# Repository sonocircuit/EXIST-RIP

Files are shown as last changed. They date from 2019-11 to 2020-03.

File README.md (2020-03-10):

# EXI[S]T: an adaption of Mannequins' RIP module.

Mannequins RIP module by Whimsical Raps is now [open source](https://github.com/whimsicalraps/RIP_DIY). EXI[S]T is an adaption thereof and can be configured in several ways. The name is a tribute to Meng Qi's module "Please Exist".

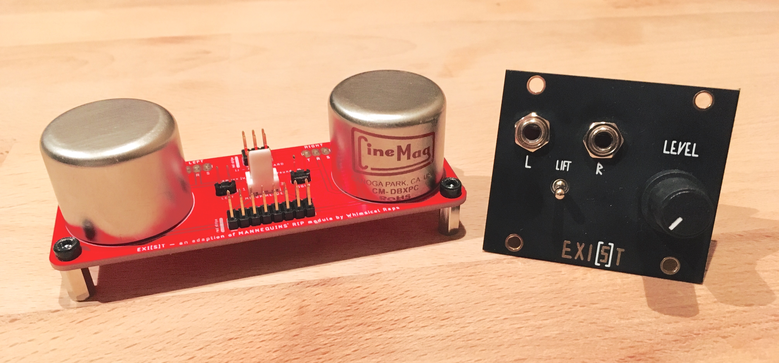
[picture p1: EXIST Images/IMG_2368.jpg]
PCB


## Modes of use

The main PCB – *the transformer board* – is meant to be mounted inside the case. The inputs and outputs can be connected in serveral ways. Any configuration of the listed options below is possible.

**Input option A:** <br> The inputs are conncted to the *transformer board* via 16 pin ribbon cable from the 1u EXI[S]T module. The 1u modules are available in Intellijel (12HP) and Pulplogic (10HP) format and house the input jacks, lift switch and an attenuating volume pot. <br>

**Input option B:** <br> An [Intelligel Mixup](https://intellijel.com/shop/eurorack/mixup) module can be connceted directly to the *transformer board* via the molex 3pin output bus connector. This configuration makes the 1u module redundant and ground lift may be engaged directly on the transformer board with two jumpers.

**Output option A:** <br> TRS Jacks can be connected to the *transformer board* with wires via the "TRS" pads. <br>

**Output option B:** <br> The 6pin header can be connected either to an Intellijel [Audio Jack rev2 board](https://intellijel.com/shop/cases/7u-audio-jacks-board-v2) or an Intellijel [Stereo Line Out Jacks module](https://intellijel.com/shop/eurorack/1u/stereo-line-out-jacks-1u) via 6 pin ribbon cable.

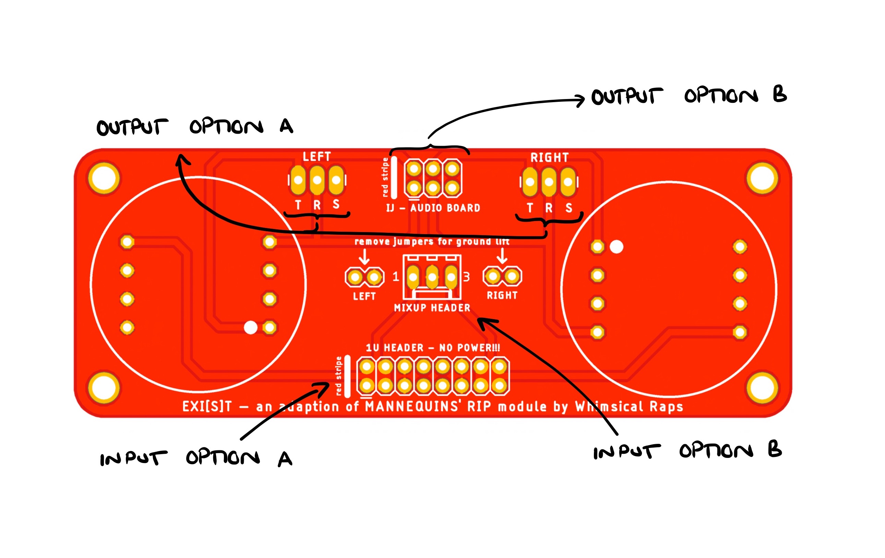
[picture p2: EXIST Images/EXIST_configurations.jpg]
CONFIG


## Make you own

**PCBs:** All [eagle files](https://github.com/sonoCircuits/EXIST-RIP/tree/master/EXIST-EAGLE%20FILES) can be found in the repro in case you wish to have PCB's fabricated.

**BOM:** Here is the [OCTOPART BOM](https://octopart.com/bom-tool/6HVkKHyi). Please note that the silkscreen of the mixup header on the *transformer board* should be rotated by 180° (rotate the header before soldering, otherwise L and R channels will be swapped). The silkscreen has been corrected on the Eagle files.

## Credits

Thanks to [Whimsical Raps](http://whimsicalraps.com) for designing RIP and making the files open source, and to Meng Qi for the name inspiration.

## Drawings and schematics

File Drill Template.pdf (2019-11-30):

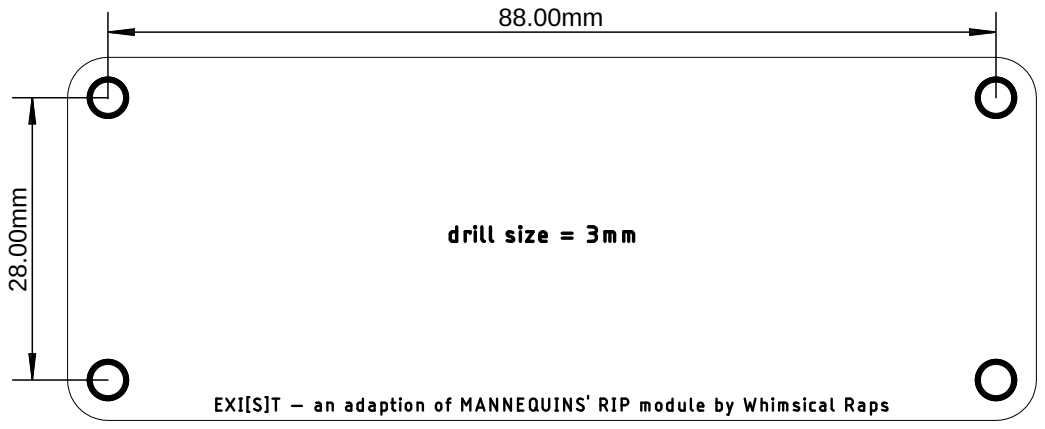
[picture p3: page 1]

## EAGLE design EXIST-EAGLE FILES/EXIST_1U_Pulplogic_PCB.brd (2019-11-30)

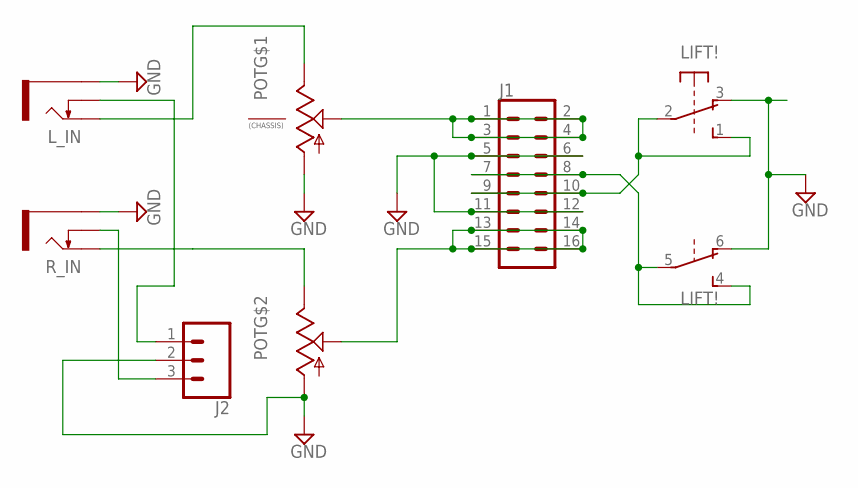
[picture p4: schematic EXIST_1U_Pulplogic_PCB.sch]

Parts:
J1: CONN_08X2; 2X8
J2: CONN_03; 1X03
LIFT!: 9450-2
L_IN: THONKICONNNEW; WQP-PJ301M-12_JACK
POT: ALPHA-9MM-DUALPOT; DUAL_9MM_SNAP-IN_POT
R_IN: THONKICONNNEW; WQP-PJ301M-12_JACK

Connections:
GND: J1.5, J1.6, J1.11, J1.12, J2.2, LIFT!.3 (O), LIFT!.6 (O), L_IN.P$3_SLEEVE (SLEEVE), POT.1 (A), POT.1B (A), R_IN.P$3_SLEEVE (SLEEVE)
unnamed: J1.13, J1.14, J1.15, J1.16, POT.2B (S)
unnamed: J1.1, J1.2, J1.3, J1.4, POT.2 (S)
unnamed: J1.7, J1.8, LIFT!.4 (S), LIFT!.5
unnamed: J2.1, L_IN.P$2_SWITCH (SWITCH)
unnamed: POT.3B (E), R_IN.P$1_TIP (TIP)
unnamed: L_IN.P$1_TIP (TIP), POT.3 (E)
unnamed: J2.3, R_IN.P$2_SWITCH (SWITCH)
unnamed: J1.9, J1.10, LIFT!.1 (S), LIFT!.2

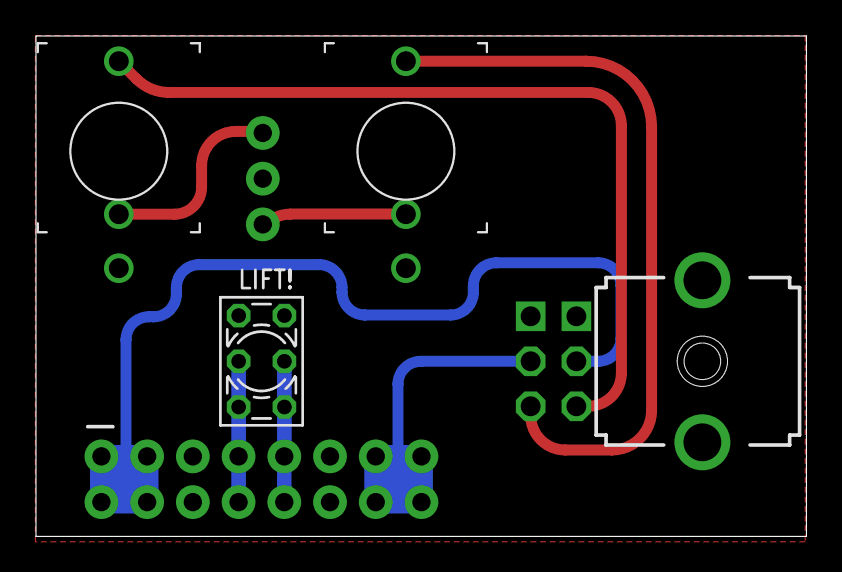
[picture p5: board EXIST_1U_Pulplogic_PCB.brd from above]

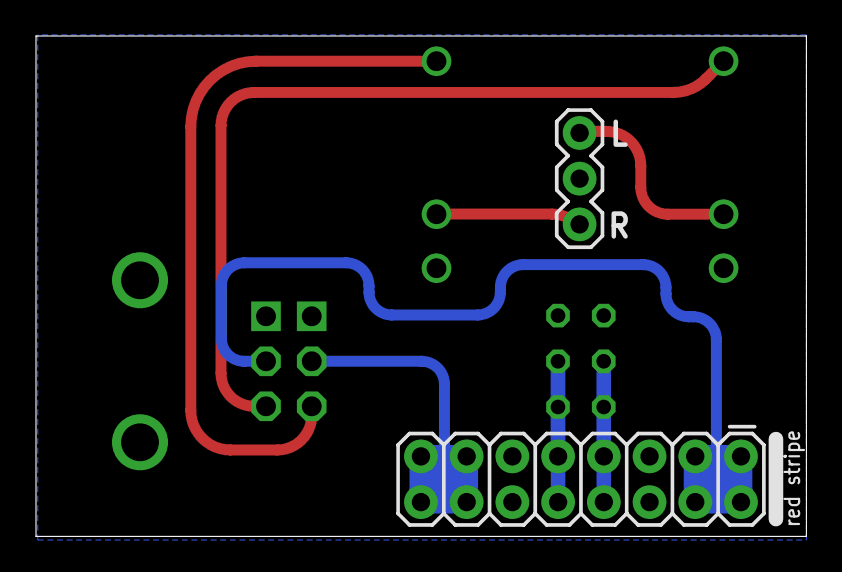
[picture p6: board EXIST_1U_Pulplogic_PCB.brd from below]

Board: 2 copper layers, 42.8 x 27.8 mm, 6 parts (2 on the bottom side), 9 nets.

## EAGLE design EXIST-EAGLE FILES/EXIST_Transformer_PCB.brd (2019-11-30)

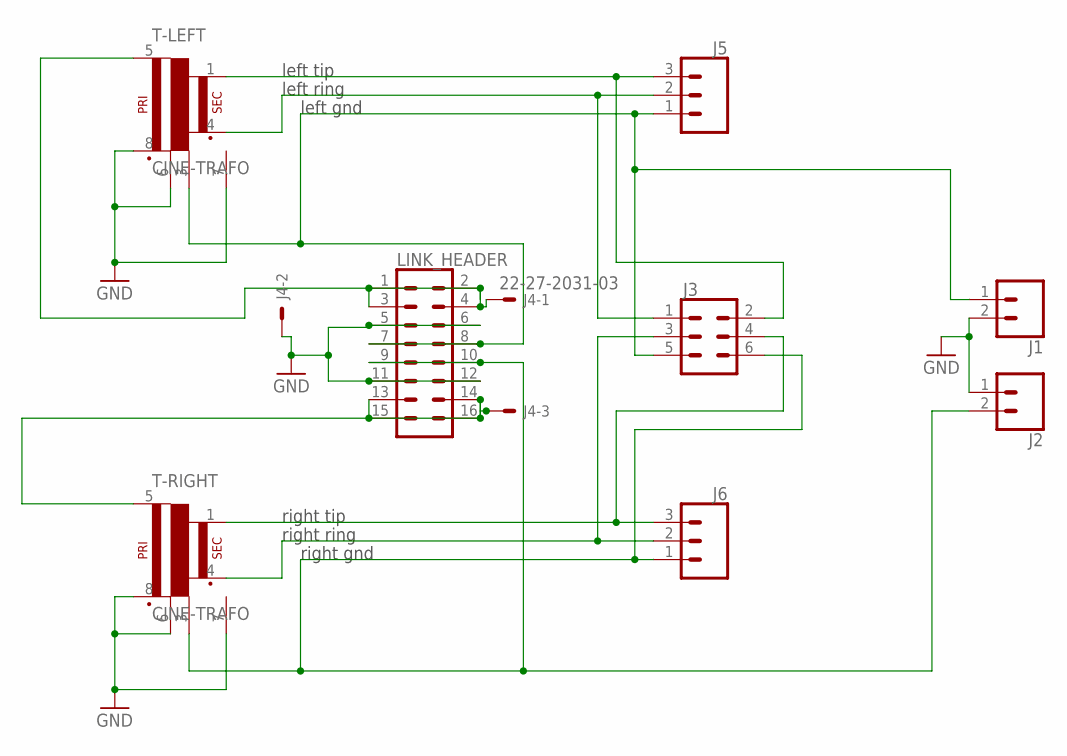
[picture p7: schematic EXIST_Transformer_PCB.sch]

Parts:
J1, J2: CONN_02; 1X02
J3: CONN_03X22X3_SILK_MALE_PTH; 2X3
J4: 22-27-2031-03; 6410-03
J5, J6: CONN_03LONGPADS; 1X03_LONGPADS
LINK_HEADER: CONN_08X2; 2X8
T-LEFT: CINE-TRAFO; CIRC-TRAFO
T-RIGHT: CINE-TRAFO; CIRC-TRAFO

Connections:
GND: J1.2, J2.1, J4.2, LINK_HEADER.5, LINK_HEADER.6, LINK_HEADER.11, LINK_HEADER.12, T-LEFT.6 (C1), T-LEFT.7 (CASE), T-LEFT.8 (P2), T-RIGHT.6 (C1), T-RIGHT.7 (CASE), T-RIGHT.8 (P2)
LEFT-GND: J1.1, J3.5, J5.1, LINK_HEADER.7, LINK_HEADER.8, T-LEFT.3 (C2)
LEFT-RING: J3.1, J5.2, T-LEFT.4 (S2)
unnamed: J3.2, J5.3, T-LEFT.1 (S1)
unnamed: J3.4, J6.3, T-RIGHT.1 (S1)
unnamed: J3.3, J6.2, T-RIGHT.4 (S2)
unnamed: J4.3, LINK_HEADER.13, LINK_HEADER.14, LINK_HEADER.15, LINK_HEADER.16, T-RIGHT.5 (P1)
unnamed: J4.1, LINK_HEADER.1, LINK_HEADER.2, LINK_HEADER.3, LINK_HEADER.4, T-LEFT.5 (P1)
RIGHT-GND: J2.2, J3.6, J6.1, LINK_HEADER.9, LINK_HEADER.10, T-RIGHT.3 (C2)

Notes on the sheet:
left tip
left ring
left gnd
right tip
right ring
right gnd

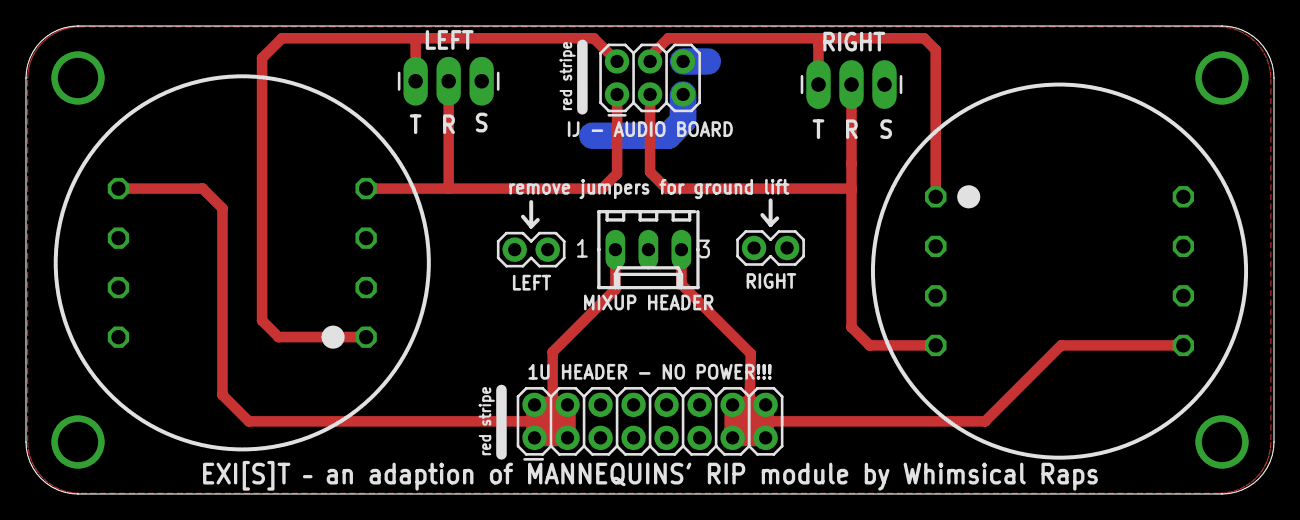
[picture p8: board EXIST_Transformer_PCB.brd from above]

Board: 2 copper layers, 96.0 x 36.0 mm, 9 parts (0 on the bottom side), 9 nets.

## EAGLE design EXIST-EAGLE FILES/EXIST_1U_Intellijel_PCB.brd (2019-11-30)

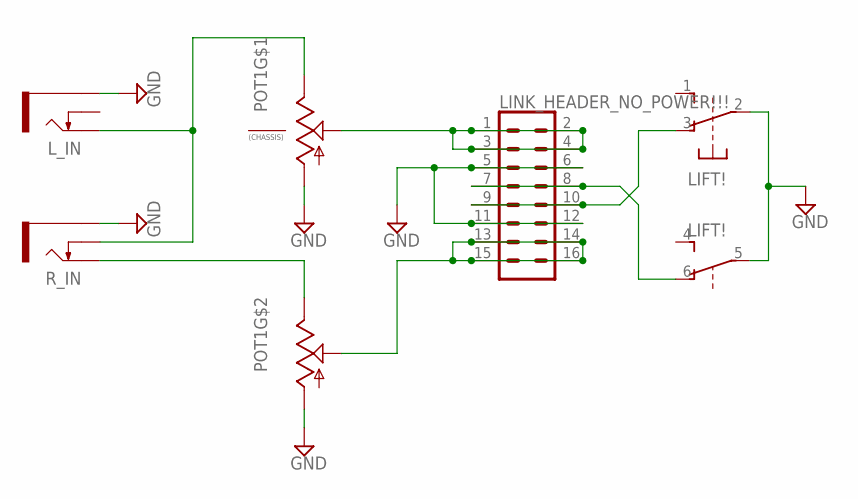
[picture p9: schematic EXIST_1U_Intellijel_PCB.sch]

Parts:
LIFT!: 9450-2
LINK_HEADER_NO_POWER!!!: CONN_08X2; 2X8
L_IN: THONKICONNNEW; WQP-PJ301M-12_JACK
POT1: ALPHA-9MM-DUALPOT; DUAL_9MM_SNAP-IN_POT
R_IN: THONKICONNNEW; WQP-PJ301M-12_JACK

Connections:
GND: LIFT!.2, LIFT!.5, LINK_HEADER_NO_POWER!!!.5, LINK_HEADER_NO_POWER!!!.6, LINK_HEADER_NO_POWER!!!.11, LINK_HEADER_NO_POWER!!!.12, L_IN.P$3_SLEEVE (SLEEVE), POT1.1 (A), POT1.1B (A), R_IN.P$3_SLEEVE (SLEEVE)
unnamed: LINK_HEADER_NO_POWER!!!.13, LINK_HEADER_NO_POWER!!!.14, LINK_HEADER_NO_POWER!!!.15, LINK_HEADER_NO_POWER!!!.16, POT1.2B (S)
unnamed: LINK_HEADER_NO_POWER!!!.1, LINK_HEADER_NO_POWER!!!.2, LINK_HEADER_NO_POWER!!!.3, LINK_HEADER_NO_POWER!!!.4, POT1.2 (S)
unnamed: LIFT!.6 (O), LINK_HEADER_NO_POWER!!!.7, LINK_HEADER_NO_POWER!!!.8
unnamed: LIFT!.3 (O), LINK_HEADER_NO_POWER!!!.9, LINK_HEADER_NO_POWER!!!.10
unnamed: POT1.3B (E), R_IN.P$1_TIP (TIP)
unnamed: L_IN.P$1_TIP (TIP), POT1.3 (E), R_IN.P$2_SWITCH (SWITCH)

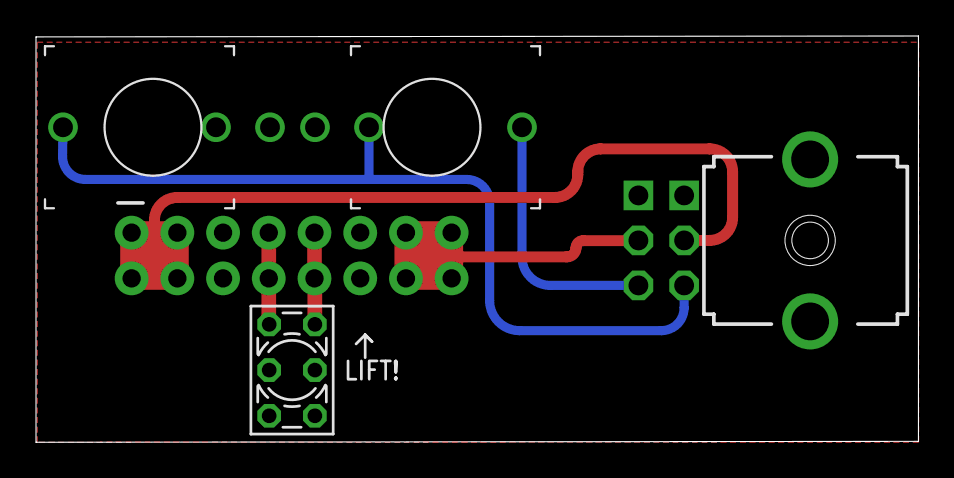
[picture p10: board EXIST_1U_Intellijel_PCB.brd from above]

Board: 2 copper layers, 49.0 x 22.6 mm, 5 parts (1 on the bottom side), 7 nets.

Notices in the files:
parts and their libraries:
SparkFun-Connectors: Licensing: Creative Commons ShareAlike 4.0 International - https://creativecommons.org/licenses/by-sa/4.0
